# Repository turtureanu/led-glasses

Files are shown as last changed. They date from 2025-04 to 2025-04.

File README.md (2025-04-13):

# led-glasses

Simple LED glasses controlled using a XIAO ESP32-S3 microcontroller.

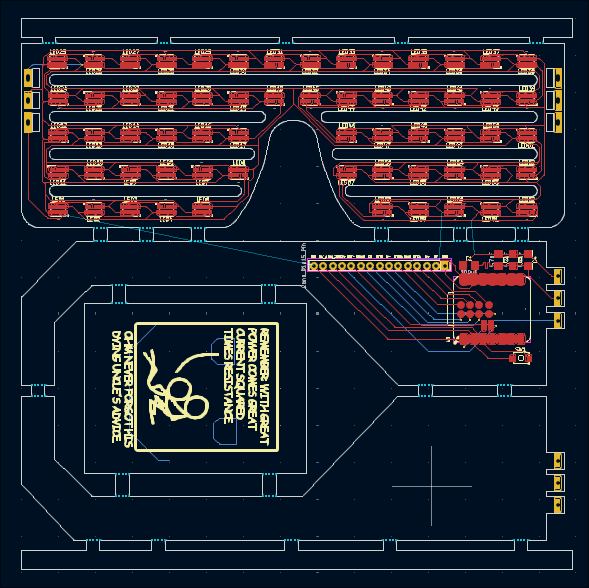
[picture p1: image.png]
PCB

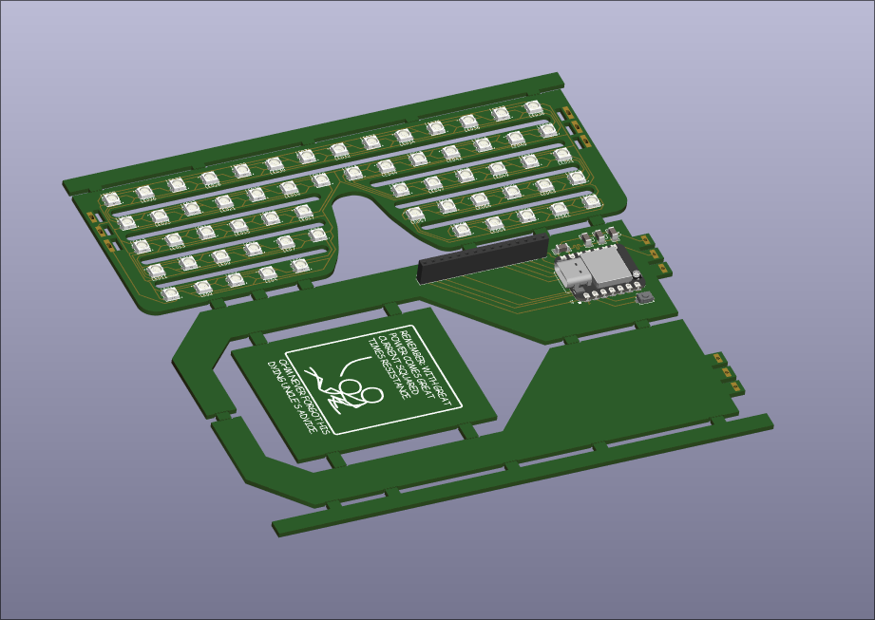
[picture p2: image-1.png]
PCB 3D


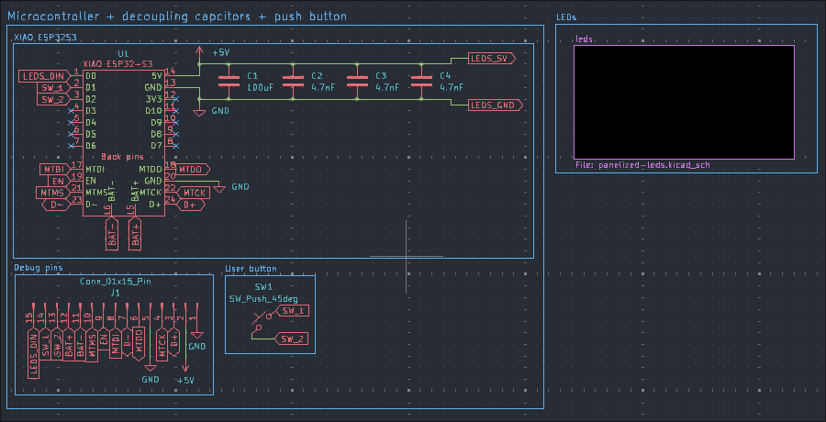
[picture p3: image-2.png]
schematic 1

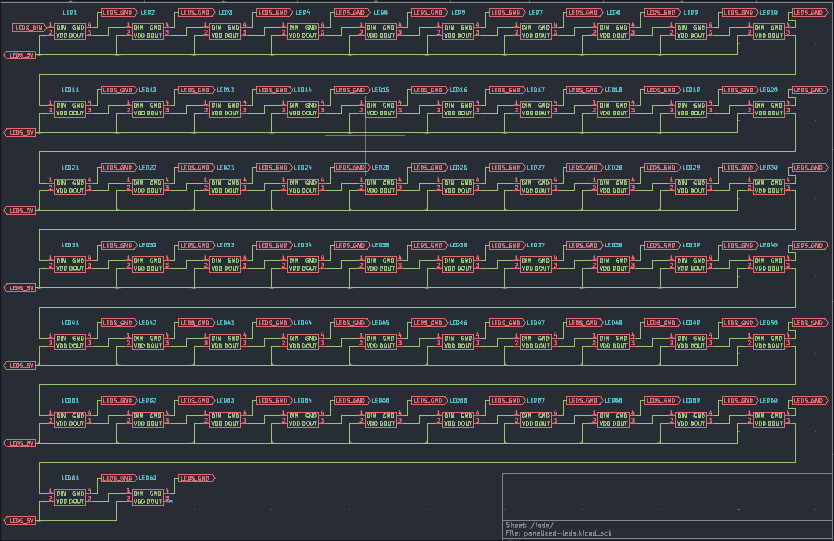
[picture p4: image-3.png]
schematic 2


## Credits

XIAO ESP32S3 footprint (XIAO-ESP32S3-SMD.kicad_mod): https://github.com/Seeed-Studio/OPL_Kicad_Library
XIAO ESP32S3 3D model: https://wiki.seeedstudio.com/xiao_esp32s3_getting_started/

Other 3D models sourced from EasyEDA.

## Todo

[-] Add battery switch circuit
[-] switch from 5V to 3V3, because 5V doesn't work with a battery
// breakout pins can be used to make a prototype using a battery
[x] breakout other pins

## BOM

- 62x | SK6812 LEDs: OPSCO Optoelectronics SK6812mini-012
  - https://www.lcsc.com/product-detail/RGB-LEDs-Built-in-IC_OPSCO-Optoelectronics-SK6812mini-012_C2886570.html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
- 1x | 1uF capacitor: Samsung Electro-Mechanics CL31A107MQHNNNE
  - https://www.lcsc.com/product-detail/Multilayer-Ceramic-Capacitors-MLCC-SMD-SMT_Samsung-Electro-Mechanics-CL31A107MQHNNNE_C15008.html
- 3x | 4.7 nF capacitor: FH (Guangdong Fenghua Advanced Tech) 1206B472K102NT
  - https://www.lcsc.com/product-detail/Multilayer-Ceramic-Capacitors-MLCC-SMD-SMT_FH-Guangdong-Fenghua-Advanced-Tech-1206B472K102NT_C9192.html
- 1x | Tactile Switch: XUNPU TS-1088-AR02016
  - https://www.lcsc.com/product-detail/Tactile-Switches_XUNPU-TS-1088-AR02016_C720477.html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

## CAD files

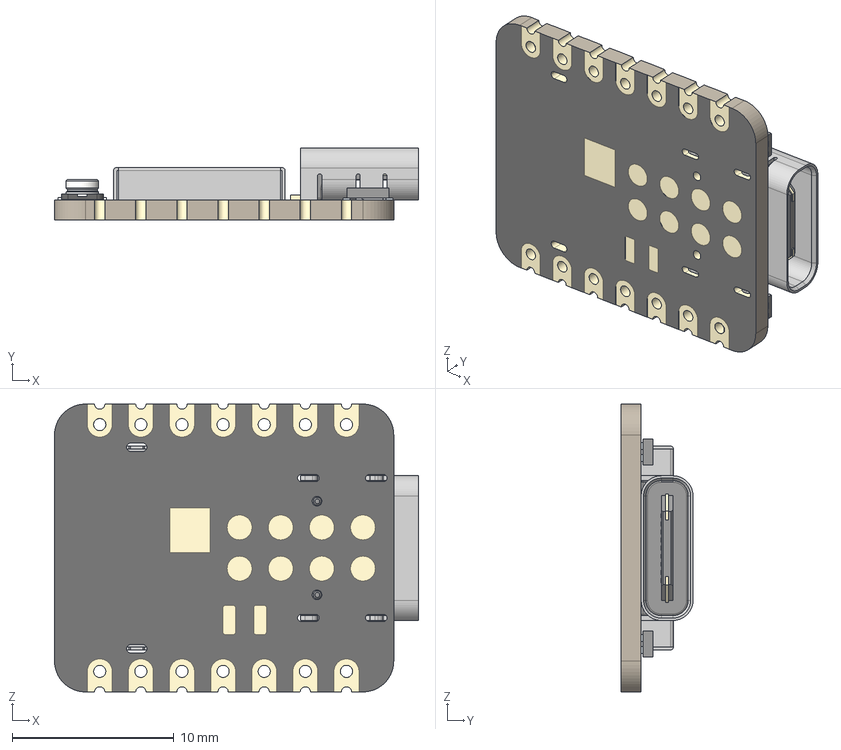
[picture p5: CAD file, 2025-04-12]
src/kicad/3d-models/XIAO-ESP32S3 v2.step
22.5 x 4.46 x 17.8 mm
BOSS-EXTRUDE14_8_
BOSS-EXTRUDE7_4_
BOSS-EXTRUDE7_3_
BOSS-EXTRUDE14_4_
BOSS-EXTRUDE14_2_
BOSS-EXTRUDE14_11_
BOSS-EXTRUDE7_7_
BOSS-EXTRUDE14_9_
BOSS-EXTRUDE14_3_
BOSS-EXTRUDE14_7_
MIRROR2
BOSS-EXTRUDE14_5_
BOSS-EXTRUDE14_12_
BOSS-EXTRUDE7_8_
BOSS-EXTRUDE7_1_
BOSS-EXTRUDE14_10_
BOSS-EXTRUDE7_9_
BOSS-EXTRUDE14_6_
BOSS-EXTRUDE14_1_
BOSS-EXTRUDE7_6_
BOSS-EXTRUDE7_2_
CUT-EXTRUDE5
BOSS-EXTRUDE7_5_
Shield
Pins x 2
U.FL-R-SMT-1_10_ v1

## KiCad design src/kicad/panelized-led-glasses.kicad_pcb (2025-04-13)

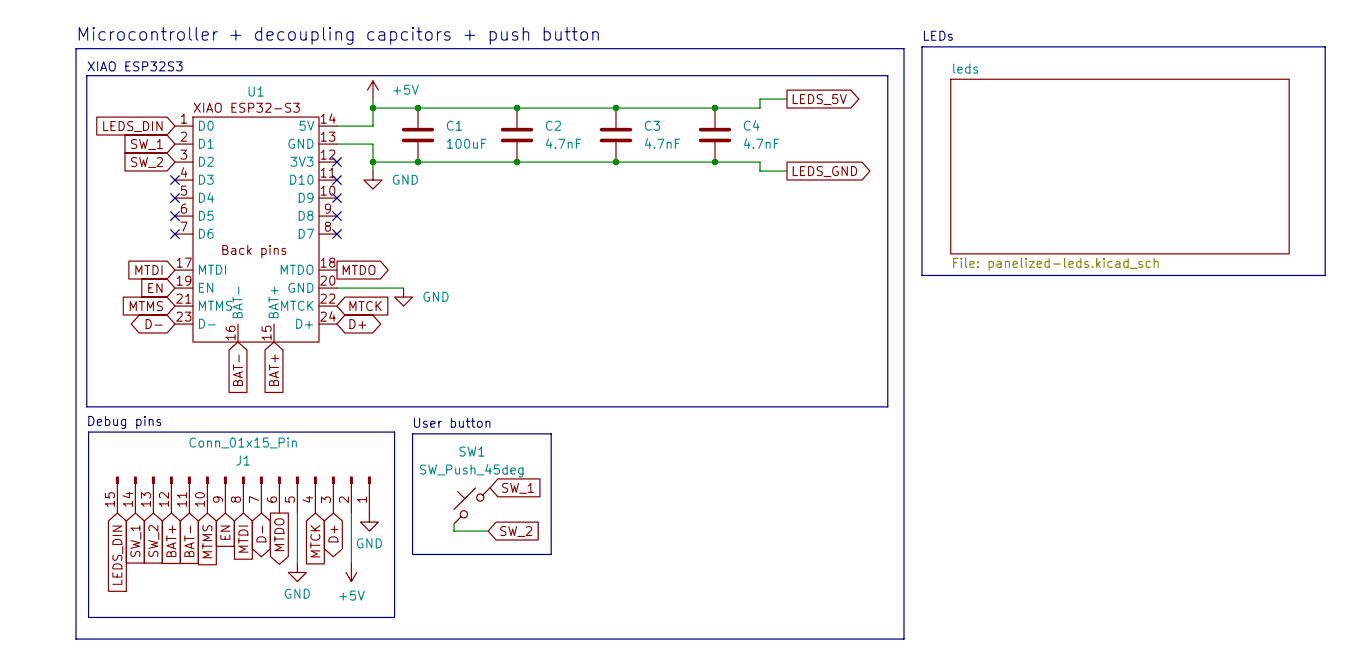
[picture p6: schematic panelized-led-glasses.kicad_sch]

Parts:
C1: 100uF; Capacitor_C1206_SMD
C2, C3, C4: 4.7nF; Capacitor_C1206_SMD
J1: Conn_01x15_Pin; PinSocket_1x15_P2.54mm_Vertical
SW1: SW_Push_45deg; SW-SMD_L3.9-W3.0-P4.45
U1: XIAO-ESP32S3-SMD

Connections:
BAT+: J1.12, U1.15 (BAT+)
BAT-: J1.11, U1.16 (BAT-)
D+: J1.3, U1.24 (D+)
D-: J1.7, U1.23 (D-)
EN: J1.9, U1.19 (EN)
LEDS_5V: C1.1, C2.1, C3.1, C4.1, J1.2, U1.14 (5V); also elsewhere on the board
LEDS_DIN: J1.15, U1.1 (D0); also elsewhere on the board
LEDS_GND: C1.2, C2.2, C3.2, C4.2, J1.1, J1.5, U1.13 (GND), U1.20 (GND); also elsewhere on the board
MTCK: J1.4, U1.22 (MTCK)
MTDI: J1.8, U1.17 (MTDI)
MTDO: J1.6, U1.18 (MTDO)
MTMS: J1.10, U1.21 (MTMS)
SW_1: J1.14, SW1.1, U1.2 (D1)
SW_2: J1.13, SW1.2, U1.3 (D2)

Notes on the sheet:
Microcontroller + decoupling capcitors + push button
User button
XIAO ESP32S3
Debug pins
LEDs

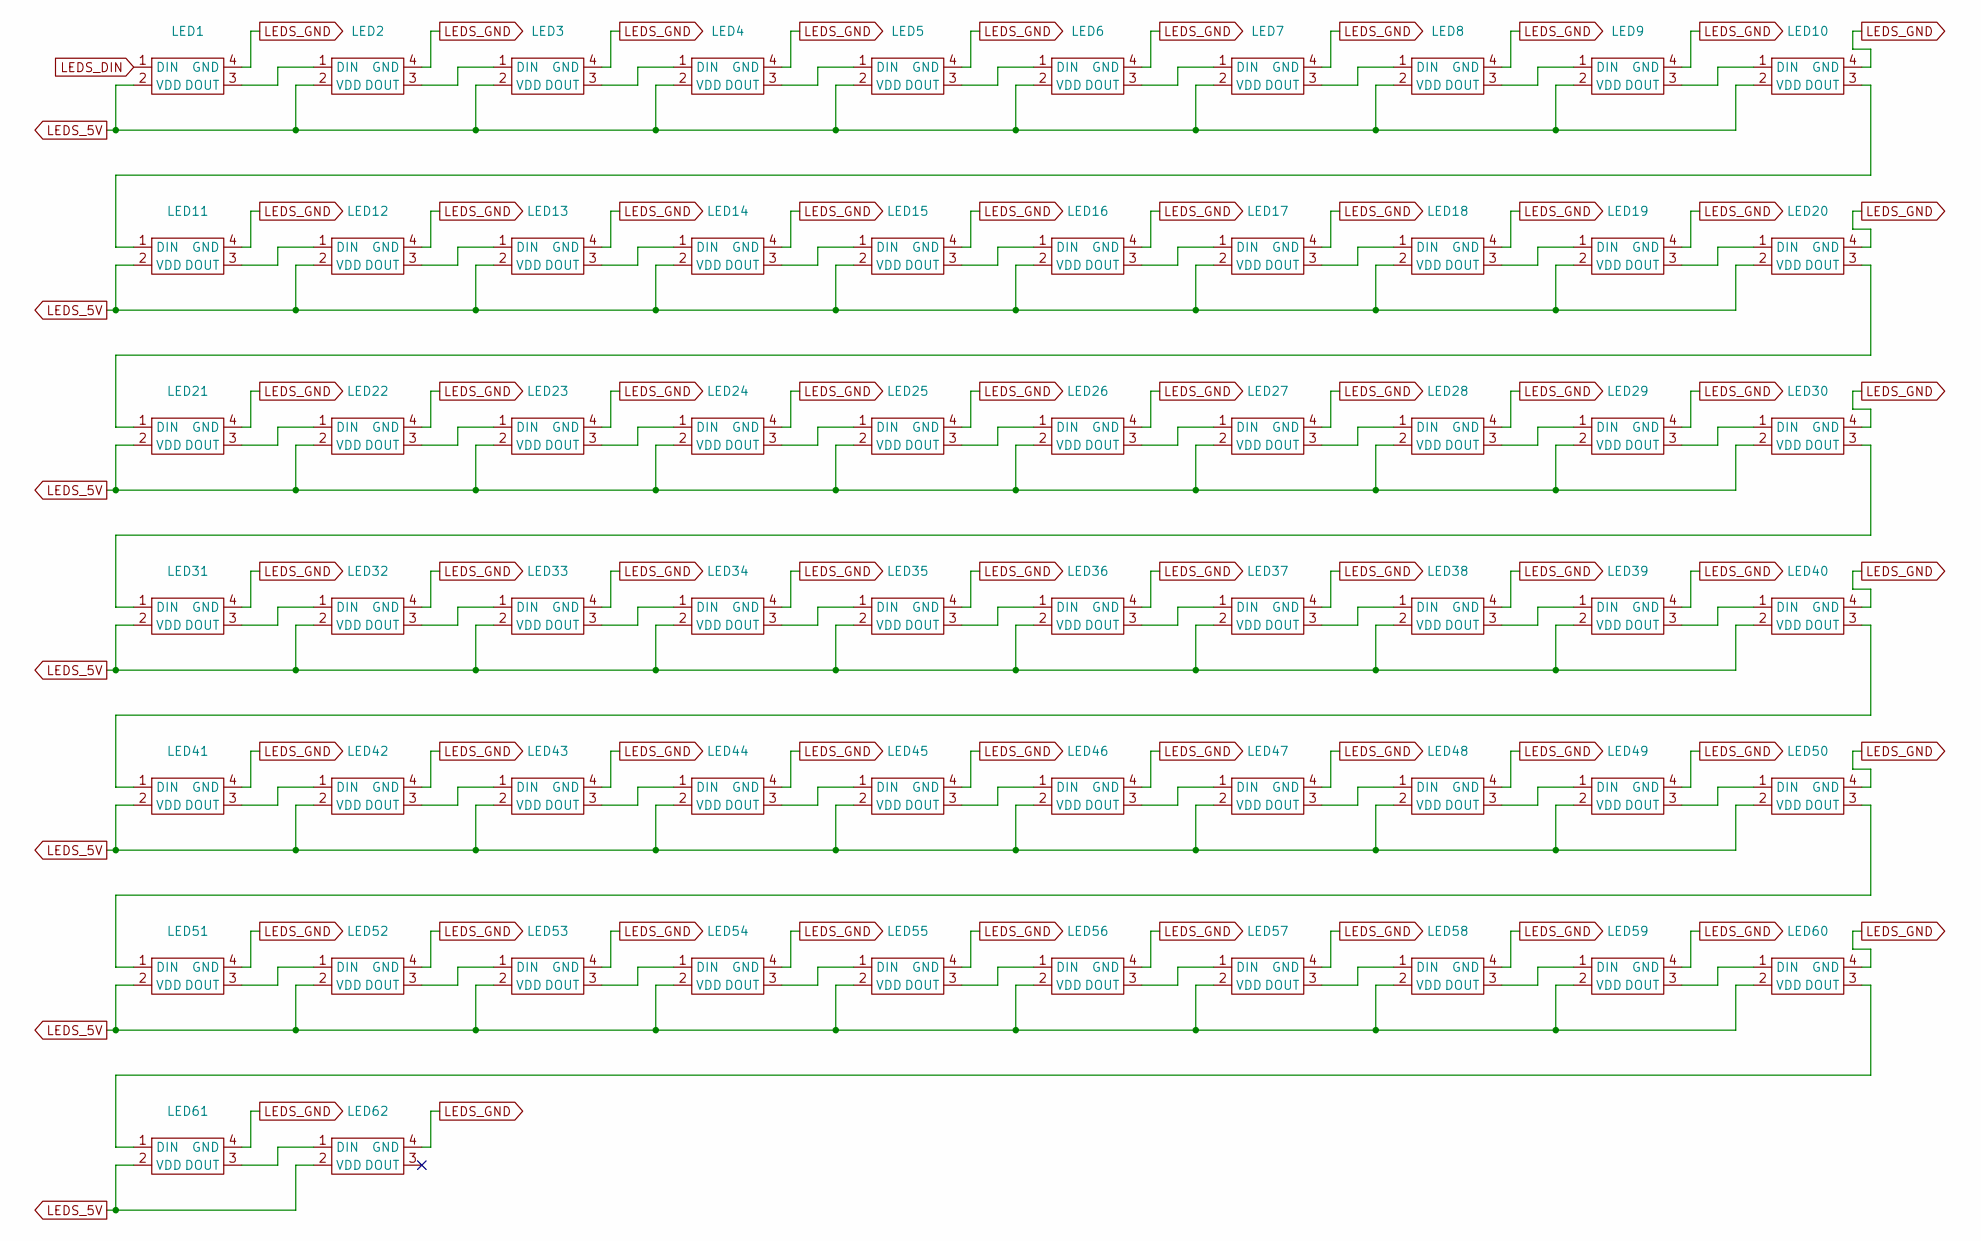
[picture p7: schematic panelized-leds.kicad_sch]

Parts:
LED1, LED2, LED3, LED4, LED5, LED6, LED7, LED8, LED9, LED10, LED11, LED12, LED13, LED14, LED15, LED16, LED17, LED18, LED19, LED20, LED21, LED22, LED23, LED24, LED25, LED26, LED27, LED28, LED29, LED30, LED31, LED32, LED33, LED34, LED35, LED36, LED37, LED38, LED39, LED40, LED41, LED42, LED43, LED44, LED45, LED46, LED47, LED48, LED49, LED50, LED51, LED52, LED53, LED54, LED55, LED56, LED57, LED58, LED59, LED60, LED61, LED62: LED-SMD_4P-L3.7-W3.5-P1.75-BR-SK6812MINI

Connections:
LEDS_5V: LED1.2 (VDD), LED2.2 (VDD), LED3.2 (VDD), LED4.2 (VDD), LED5.2 (VDD), LED6.2 (VDD), LED7.2 (VDD), LED8.2 (VDD), LED9.2 (VDD), LED10.2 (VDD), LED11.2 (VDD), LED12.2 (VDD), LED13.2 (VDD), LED14.2 (VDD), LED15.2 (VDD), LED16.2 (VDD), LED17.2 (VDD), LED18.2 (VDD), LED19.2 (VDD), LED20.2 (VDD), LED21.2 (VDD), LED22.2 (VDD), LED23.2 (VDD), LED24.2 (VDD), LED25.2 (VDD), LED26.2 (VDD), LED27.2 (VDD), LED28.2 (VDD), LED29.2 (VDD), LED30.2 (VDD), LED31.2 (VDD), LED32.2 (VDD), LED33.2 (VDD), LED34.2 (VDD), LED35.2 (VDD), LED36.2 (VDD), LED37.2 (VDD), LED38.2 (VDD), LED39.2 (VDD), LED40.2 (VDD), LED41.2 (VDD), LED42.2 (VDD), LED43.2 (VDD), LED44.2 (VDD), LED45.2 (VDD), LED46.2 (VDD), LED47.2 (VDD), LED48.2 (VDD), LED49.2 (VDD), LED50.2 (VDD), LED51.2 (VDD), LED52.2 (VDD), LED53.2 (VDD), LED54.2 (VDD), LED55.2 (VDD), LED56.2 (VDD), LED57.2 (VDD), LED58.2 (VDD), LED59.2 (VDD), LED60.2 (VDD), LED61.2 (VDD), LED62.2 (VDD); also elsewhere on the board
LEDS_DIN: LED1.1 (DIN); also elsewhere on the board
LEDS_GND: LED1.4 (GND), LED2.4 (GND), LED3.4 (GND), LED4.4 (GND), LED5.4 (GND), LED6.4 (GND), LED7.4 (GND), LED8.4 (GND), LED9.4 (GND), LED10.4 (GND), LED11.4 (GND), LED12.4 (GND), LED13.4 (GND), LED14.4 (GND), LED15.4 (GND), LED16.4 (GND), LED17.4 (GND), LED18.4 (GND), LED19.4 (GND), LED20.4 (GND), LED21.4 (GND), LED22.4 (GND), LED23.4 (GND), LED24.4 (GND), LED25.4 (GND), LED26.4 (GND), LED27.4 (GND), LED28.4 (GND), LED29.4 (GND), LED30.4 (GND), LED31.4 (GND), LED32.4 (GND), LED33.4 (GND), LED34.4 (GND), LED35.4 (GND), LED36.4 (GND), LED37.4 (GND), LED38.4 (GND), LED39.4 (GND), LED40.4 (GND), LED41.4 (GND), LED42.4 (GND), LED43.4 (GND), LED44.4 (GND), LED45.4 (GND), LED46.4 (GND), LED47.4 (GND), LED48.4 (GND), LED49.4 (GND), LED50.4 (GND), LED51.4 (GND), LED52.4 (GND), LED53.4 (GND), LED54.4 (GND), LED55.4 (GND), LED56.4 (GND), LED57.4 (GND), LED58.4 (GND), LED59.4 (GND), LED60.4 (GND), LED61.4 (GND), LED62.4 (GND); also elsewhere on the board
unnamed: LED1.3 (DOUT), LED2.1 (DIN)
unnamed: LED2.3 (DOUT), LED3.1 (DIN)
unnamed: LED3.3 (DOUT), LED4.1 (DIN)
unnamed: LED4.3 (DOUT), LED5.1 (DIN)
unnamed: LED5.3 (DOUT), LED6.1 (DIN)
unnamed: LED6.3 (DOUT), LED7.1 (DIN)
unnamed: LED7.3 (DOUT), LED8.1 (DIN)
unnamed: LED8.3 (DOUT), LED9.1 (DIN)
unnamed: LED9.3 (DOUT), LED10.1 (DIN)
unnamed: LED10.3 (DOUT), LED11.1 (DIN)
unnamed: LED11.3 (DOUT), LED12.1 (DIN)
unnamed: LED12.3 (DOUT), LED13.1 (DIN)
unnamed: LED13.3 (DOUT), LED14.1 (DIN)
unnamed: LED14.3 (DOUT), LED15.1 (DIN)
unnamed: LED15.3 (DOUT), LED16.1 (DIN)
unnamed: LED16.3 (DOUT), LED17.1 (DIN)
unnamed: LED17.3 (DOUT), LED18.1 (DIN)
unnamed: LED18.3 (DOUT), LED19.1 (DIN)
unnamed: LED19.3 (DOUT), LED20.1 (DIN)
unnamed: LED20.3 (DOUT), LED21.1 (DIN)
unnamed: LED21.3 (DOUT), LED22.1 (DIN)
unnamed: LED22.3 (DOUT), LED23.1 (DIN)
unnamed: LED23.3 (DOUT), LED24.1 (DIN)
unnamed: LED24.3 (DOUT), LED25.1 (DIN)
unnamed: LED25.3 (DOUT), LED26.1 (DIN)
unnamed: LED26.3 (DOUT), LED27.1 (DIN)
unnamed: LED27.3 (DOUT), LED28.1 (DIN)
unnamed: LED28.3 (DOUT), LED29.1 (DIN)
unnamed: LED29.3 (DOUT), LED30.1 (DIN)
unnamed: LED30.3 (DOUT), LED31.1 (DIN)
unnamed: LED31.3 (DOUT), LED32.1 (DIN)
unnamed: LED32.3 (DOUT), LED33.1 (DIN)
unnamed: LED33.3 (DOUT), LED34.1 (DIN)
unnamed: LED34.3 (DOUT), LED35.1 (DIN)
unnamed: LED35.3 (DOUT), LED36.1 (DIN)
unnamed: LED36.3 (DOUT), LED37.1 (DIN)
unnamed: LED37.3 (DOUT), LED38.1 (DIN)
unnamed: LED38.3 (DOUT), LED39.1 (DIN)
unnamed: LED39.3 (DOUT), LED40.1 (DIN)
unnamed: LED40.3 (DOUT), LED41.1 (DIN)
unnamed: LED41.3 (DOUT), LED42.1 (DIN)
unnamed: LED42.3 (DOUT), LED43.1 (DIN)
unnamed: LED43.3 (DOUT), LED44.1 (DIN)
unnamed: LED44.3 (DOUT), LED45.1 (DIN)
unnamed: LED45.3 (DOUT), LED46.1 (DIN)
unnamed: LED46.3 (DOUT), LED47.1 (DIN)
unnamed: LED47.3 (DOUT), LED48.1 (DIN)
unnamed: LED48.3 (DOUT), LED49.1 (DIN)
unnamed: LED49.3 (DOUT), LED50.1 (DIN)
unnamed: LED50.3 (DOUT), LED51.1 (DIN)
unnamed: LED51.3 (DOUT), LED52.1 (DIN)
unnamed: LED52.3 (DOUT), LED53.1 (DIN)
unnamed: LED53.3 (DOUT), LED54.1 (DIN)
unnamed: LED54.3 (DOUT), LED55.1 (DIN)
unnamed: LED55.3 (DOUT), LED56.1 (DIN)
unnamed: LED56.3 (DOUT), LED57.1 (DIN)
unnamed: LED57.3 (DOUT), LED58.1 (DIN)
unnamed: LED58.3 (DOUT), LED59.1 (DIN)
unnamed: LED59.3 (DOUT), LED60.1 (DIN)
unnamed: LED60.3 (DOUT), LED61.1 (DIN)
unnamed: LED61.3 (DOUT), LED62.1 (DIN)

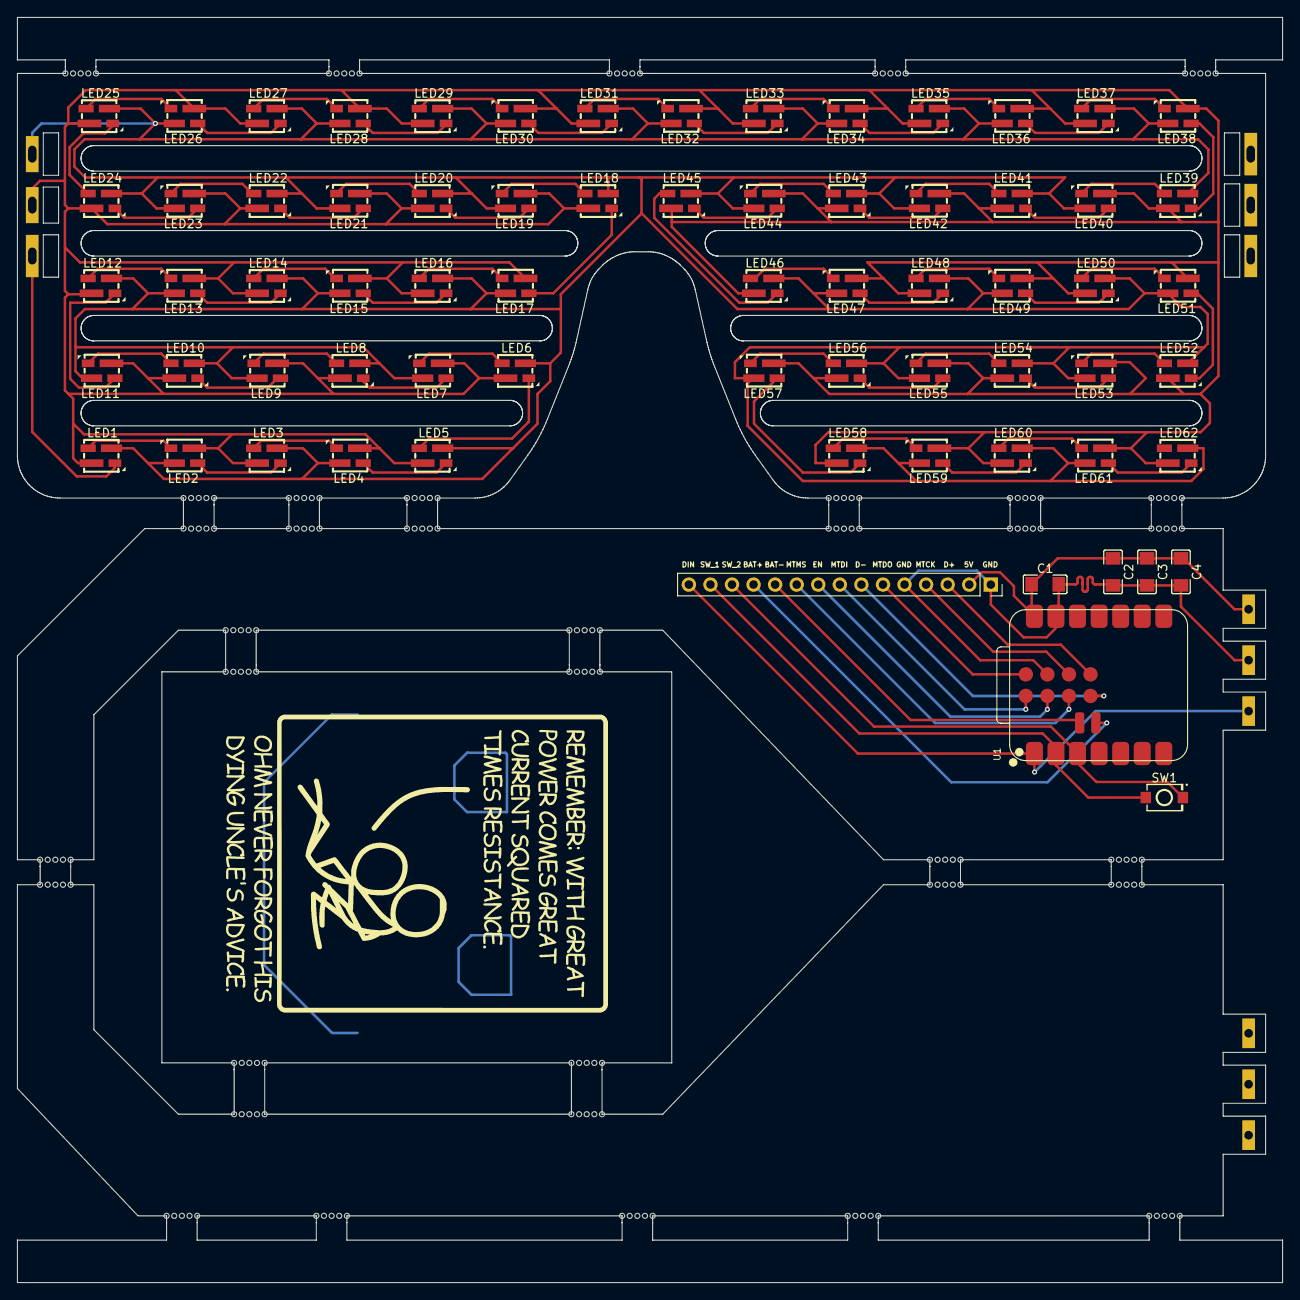
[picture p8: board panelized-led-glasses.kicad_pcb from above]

Board: 2 copper layers, 149.0 x 149.0 mm, 184 parts (0 on the bottom side), 75 nets.

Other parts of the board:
KiKit_MB_1_1, KiKit_MB_1_2, KiKit_MB_1_3, KiKit_MB_1_4, KiKit_MB_1_5, KiKit_MB_2_1, KiKit_MB_2_2, KiKit_MB_2_3, KiKit_MB_2_4, KiKit_MB_2_5, KiKit_MB_3_1, KiKit_MB_3_2, KiKit_MB_3_3, KiKit_MB_3_4, KiKit_MB_3_5, KiKit_MB_4_1, KiKit_MB_4_2, KiKit_MB_4_3, KiKit_MB_4_4, KiKit_MB_4_5, KiKit_MB_5_1, KiKit_MB_5_2, KiKit_MB_5_3, KiKit_MB_5_4, KiKit_MB_5_5, KiKit_MB_6_1, KiKit_MB_6_2, KiKit_MB_6_3, KiKit_MB_6_4, KiKit_MB_6_5, KiKit_MB_7_1, KiKit_MB_7_2, KiKit_MB_7_3, KiKit_MB_7_4, KiKit_MB_7_5, KiKit_MB_8_1, KiKit_MB_8_2, KiKit_MB_8_3, KiKit_MB_8_4, KiKit_MB_8_5, KiKit_MB_9_1, KiKit_MB_9_2, KiKit_MB_9_3, KiKit_MB_9_4, KiKit_MB_9_5, KiKit_MB_10_1, KiKit_MB_10_2, KiKit_MB_10_3, KiKit_MB_10_4, KiKit_MB_10_5, KiKit_MB_11_1, KiKit_MB_11_2, KiKit_MB_11_3, KiKit_MB_11_4, KiKit_MB_11_5, KiKit_MB_12_1, KiKit_MB_12_2, KiKit_MB_12_3, KiKit_MB_12_4, KiKit_MB_12_5, KiKit_MB_13_1, KiKit_MB_13_2, KiKit_MB_13_3, KiKit_MB_13_4, KiKit_MB_13_5, KiKit_MB_14_1, KiKit_MB_14_2, KiKit_MB_14_3, KiKit_MB_14_4, KiKit_MB_14_5, KiKit_MB_15_1, KiKit_MB_15_2, KiKit_MB_15_3, KiKit_MB_15_4, KiKit_MB_15_5, KiKit_MB_16_1, KiKit_MB_16_2, KiKit_MB_16_3, KiKit_MB_16_4, KiKit_MB_16_5, KiKit_MB_17_1, KiKit_MB_17_2, KiKit_MB_17_3, KiKit_MB_17_4, KiKit_MB_17_5, KiKit_MB_18_1, KiKit_MB_18_2, KiKit_MB_18_3, KiKit_MB_18_4, KiKit_MB_18_5, KiKit_MB_19_1, KiKit_MB_19_2, KiKit_MB_19_3, KiKit_MB_19_4, KiKit_MB_19_5, KiKit_MB_20_1, KiKit_MB_20_2, KiKit_MB_20_3, KiKit_MB_20_4, KiKit_MB_20_5, KiKit_MB_21_1, KiKit_MB_21_2, KiKit_MB_21_3, KiKit_MB_21_4, KiKit_MB_21_5, KiKit_MB_22_1, KiKit_MB_22_2, KiKit_MB_22_3, KiKit_MB_22_4, KiKit_MB_22_5, KiKit_MB_23_1, KiKit_MB_23_2, KiKit_MB_23_3, KiKit_MB_23_4, KiKit_MB_23_5: NPTH

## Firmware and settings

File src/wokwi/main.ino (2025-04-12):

/*

XIAO ESP32-S3 LED Glasses

Made by @turtureanu, available on
    - Github: https://github.com/turtureanu/led-glasses
    - Wokwi: https://wokwi.com/projects/428024875914576897

Usage: press the button for 1-2 seconds then realease, after ~3 seconds the animation will change

Libraries used:
    - FastLED (MIT License, authors and contributors: https://github.com/FastLED/FastLED/graphs/contributors)

Licensed under the GPLv3 license available at https://www.gnu.org/licenses/gpl-3.0.en.html

*/

#include <FastLED.h>

#define DATA_PIN 1
#define NUM_LEDS 62
#define COLS 14
#define ROWS 5
#define SW_PIN_1 3
#define SW_PIN_2 2

CRGBArray<NUM_LEDS> leds;

// map every led to its coordinate (index)
// value: the led's number (1, 2, 3, ...)
// index: led coordinate
// -1 means missing
int ledDictionary[ROWS][COLS] = {
  {24, 25, 26, 27, 28, 29, 30, 31, 32, 33, 34, 35, 36, 37},
  {23, 22, 21, 20, 19, 18, 17, 44, 43, 42, 41, 40, 39, 38},
  {11, 12, 13, 14, 15, 16, -1, -1, 45, 46, 47, 48, 49, 50},
  {10, 9, 8, 7, 6, 5, -1, -1, 56, 55, 54, 53, 52, 51},
  {0, 1, 2, 3, 4, -1, -1, -1, -1, 57, 58, 59, 60, 61}
};

int ledGrid[ROWS][COLS][3]; // each cell has 3 values (RGB)

int animationSpeed = 250; // the animation speed

// basically do nothing until the button is pressed
void waitForButton() {
  while(digitalRead(SW_PIN_2) == LOW) {}
}

/*
===================
DISPLAY FUNCTIONS
===================

// showLedGrid(): updates leds[] according to ledGrid using ledDictionary to map the leds,
//                then executes FastLeds.show()

// COLORS
// solidRed, solidGreen, solidBlue: set static corresponding colors

// ANIMATIONS
// halfBlink: blinks one half at a time
// alternateColumns: self-explanatory, light up col %2 == 0 or col %2 == 1
// alternateRows: same as alternateColumns() but for rows
// checkers: alternating checkers pattern
// rainbow: the usual 45 degree top left to bottom right moving rainbow gradient
*/


void showLedGrid() {
  for (int i = 0; i < ROWS; i++) {
    for (int j = 0; j < COLS; j++) {
      if (ledDictionary[i][j] != -1) {
        leds[ledDictionary[i][j]].setRGB(ledGrid[i][j][0], ledGrid[i][j][1], ledGrid[i][j][2]);
      }
    }
  }

  FastLED.show();
}

void solidRed() {
  for (int i = 0; i < ROWS; i++) {
    for (int j = 0; j < COLS; j++) {
      ledGrid[i][j][0] = 255;
      ledGrid[i][j][1] = 0;
      ledGrid[i][j][2] = 0;
    }
  }

  showLedGrid();
  waitForButton();
}

void solidGreen() {
  for (int i = 0; i < ROWS; i++) {
    for (int j = 0; j < COLS; j++) {
      ledGrid[i][j][0] = 0;
      ledGrid[i][j][1] = 255;
      ledGrid[i][j][2] = 0;
    }
  }

  showLedGrid();
  waitForButton();
}

void solidBlue() {
  for (int i = 0; i < ROWS; i++) {
    for (int j = 0; j < COLS; j++) {
      ledGrid[i][j][0] = 0;
      ledGrid[i][j][1] = 0;
      ledGrid[i][j][2] = 255;
    }
  }

  showLedGrid();
  waitForButton();
}

void halfBlink() {
  while (digitalRead(SW_PIN_2) == LOW) {
    // left half
    for (int i = 0; i < ROWS; i++) {
      for (int j = 0; j < COLS; j++) {
        if (j < COLS / 2) {
          ledGrid[i][j][0] = 0;   // R
          ledGrid[i][j][1] = 80;  // G
          ledGrid[i][j][2] = 255; // B
        } else {
          ledGrid[i][j][0] = 0; // R
          ledGrid[i][j][1] = 0; // G
          ledGrid[i][j][2] = 0; // B
        }
      }
    }

    showLedGrid();
    delay(animationSpeed);

    for (int i = 0; i < ROWS; i++) {
      for (int j = 0; j < COLS; j++) {
        if (j >= COLS / 2) {
          ledGrid[i][j][0] = 0;   // R
          ledGrid[i][j][1] = 80;  // G
          ledGrid[i][j][2] = 255; // B
        } else {
          ledGrid[i][j][0] = 0; // R
          ledGrid[i][j][1] = 0; // G
          ledGrid[i][j][2] = 0; // B
        }
        
      }
    }

    showLedGrid();
    delay(animationSpeed);
  }
}

void alternateColumns() {
  while (digitalRead(SW_PIN_2) == LOW) {
    for (int i = 0; i < ROWS; i++) {
      for (int j = 0; j < COLS; j++) {
        if (j % 2 == 1) {
          ledGrid[i][j][0] = 0;   // R
          ledGrid[i][j][1] = 80;  // G
          ledGrid[i][j][2] = 255; // B
        } else {
          ledGrid[i][j][0] = 0; // R
          ledGrid[i][j][1] = 0; // G
          ledGrid[i][j][2] = 0; // B
        }
      }
    }

    showLedGrid();
    delay(animationSpeed);

    for (int i = 0; i < ROWS; i++) {
      for (int j = 0; j < COLS; j++) {
        if (j % 2 != 1) {
          ledGrid[i][j][0] = 0;   // R
          ledGrid[i][j][1] = 80;  // G
          ledGrid[i][j][2] = 255; // B
        } else {
          ledGrid[i][j][0] = 0; // R
          ledGrid[i][j][1] = 0; // G
          ledGrid[i][j][2] = 0; // B
        }
      }
    }

    showLedGrid();
    delay(animationSpeed);
  }
}

void alternateRows() {
  while (digitalRead(SW_PIN_2) == LOW) {
    for (int i = 0; i < ROWS; i++) {
      for (int j = 0; j < COLS; j++) {
        if (i % 2 == 1) {
          ledGrid[i][j][0] = 0;   // R
          ledGrid[i][j][1] = 80;  // G
          ledGrid[i][j][2] = 255; // B
        } else {
          ledGrid[i][j][0] = 0; // R
          ledGrid[i][j][1] = 0; // G
          ledGrid[i][j][2] = 0; // B
        }
      }
    }

    showLedGrid();
    delay(animationSpeed);

    for (int i = 0; i < ROWS; i++) {
      for (int j = 0; j < COLS; j++) {
        if (i % 2 != 1) {
          ledGrid[i][j][0] = 0;   // R
          ledGrid[i][j][1] = 80;  // G
          ledGrid[i][j][2] = 255; // B
        } else {
          ledGrid[i][j][0] = 0; // R
          ledGrid[i][j][1] = 0; // G
          ledGrid[i][j][2] = 0; // B
        }
      }
    }

    showLedGrid();
    delay(animationSpeed);
  }
}

void checkers() {
  while (digitalRead(SW_PIN_2) == LOW) {
    for (int i = 0; i < ROWS; i++) {
      for (int j = 0; j < COLS; j++) {
        if ((i + j) % 2 == 0) {
          ledGrid[i][j][0] = 0;   // R
          ledGrid[i][j][1] = 80;  // G
          ledGrid[i][j][2] = 255; // B
        } else {
          ledGrid[i][j][0] = 0; // R
          ledGrid[i][j][1] = 0; // G
          ledGrid[i][j][2] = 0; // B
        }
      }
    }

    showLedGrid();
    delay(animationSpeed);

    for (int i = 0; i < ROWS; i++) {
      for (int j = 0; j < COLS; j++) {
        if ((i + j) % 2 != 0) {
          ledGrid[i][j][0] = 0;   // R
          ledGrid[i][j][1] = 80;  // G
          ledGrid[i][j][2] = 255; // B
        } else {
          ledGrid[i][j][0] = 0; // R
          ledGrid[i][j][1] = 0; // G
          ledGrid[i][j][2] = 0; // B
        }
      }
    }

    showLedGrid();
    delay(animationSpeed);
  }
}


void rainbow() {
  int offset = 0;

  while (digitalRead(SW_PIN_2) == LOW) {
    for (int i = 0; i < ROWS; i++) {
      for (int j = COLS - 1; j >= 0; j--) {
        // no idea how this works
        uint8_t hue = (i + j - offset) * (255 / (COLS + ROWS));

        // get the ledColor using the hue
        CRGB ledColor = CHSV(hue, 255, 255);
        ledGrid[i][j][0] = ledColor.r;
        ledGrid[i][j][1] = ledColor.g;
        ledGrid[i][j][2] = ledColor.b;
      }
    }

    showLedGrid();
    delay(animationSpeed / 4);

    offset++;

    // reset offset (perfect loop)
    if (offset >= 255) {
      offset = 0;
    }
  }
}

void setup() {
  Serial.begin(115200);
  Serial.println("");
  Serial.println("Hello, XIAO ESP32-S3!");
  Serial.println("Welcome to Wokwi :-)");

  // set SW_PIN_1 to HIGH
  pinMode(SW_PIN_1, OUTPUT);
  digitalWrite(SW_PIN_1, HIGH);
  

  // set SW_PIN_2 as INPUT
  pinMode(SW_PIN_2, INPUT);

  FastLED.addLeds<NEOPIXEL, DATA_PIN>(leds, NUM_LEDS);

  // Boot animation
  for (int i = 0; i < NUM_LEDS; i++) {
    leds[i] = CRGB::Blue;
    FastLED.show();
    delay(10);
  }

  for (int i = 0; i < NUM_LEDS; i++) {
    leds[i] = CRGB::Black;
    FastLED.show();
    delay(10);
  }

  for (int i = 0; i < ROWS; i++) {
    for (int j = 0; j < COLS; j++) {
      ledGrid[i][j][0] = 0; // R
      ledGrid[i][j][1] = 0; // G
      ledGrid[i][j][2] = 0; // B
    }
  }
}

void loop() {
  solidRed();
  delay(3000);
  solidGreen();
  delay(3000);
  solidBlue();
  delay(3000);
  halfBlink();
  delay(3000);
  alternateColumns();
  delay(3000);
  alternateRows();
  delay(3000);
  checkers();
  delay(3000);
  rainbow();
  delay(3000);
}

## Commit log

2025-04-12 add: initial files
    [XIAO-ESP32S3 v2.step, panelized-led-glasses.kicad_pcb, panelized-led-glasses.kicad_sch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]
2025-04-13 feat: final touch ups
    [panelized-led-glasses.kicad_pcb]
